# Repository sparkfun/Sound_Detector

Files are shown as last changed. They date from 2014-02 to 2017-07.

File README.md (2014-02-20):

#Sound_detector
***

[Sound Detector  
*Sound Detector*](https://www.sparkfun.com/products/12642)  

Electret microphone with multiple outputs.

* First output is the actual audio
* Second output is the amplitude envelope
* Third output is a binary "sound present" indication - high while sound is present, low otherwise.

Design and firmware files for the [VKey Voltage Keypad](https://www.sparkfun.com/products/12080).

Repository Contents
-------------------

* **/Documents** - Additional design files including LTspice simulation  
* **/Hardware** - Eagle PCB and schematic files
* **/Production** - Production panel file
* **/Software** - Arduino example code

License Information
-------------------
The hardware is released under [Creative Commons ShareAlike 4.0 International](https://creativecommons.org/licenses/by-sa/4.0/).
The code is beerware; if you see me (or any other SparkFun employee) at the local, and you've found our code helpful, please buy us a round!

Distributed as-is; no warranty is given.

Author: Byron Jacquot @ SparkFun Electonics

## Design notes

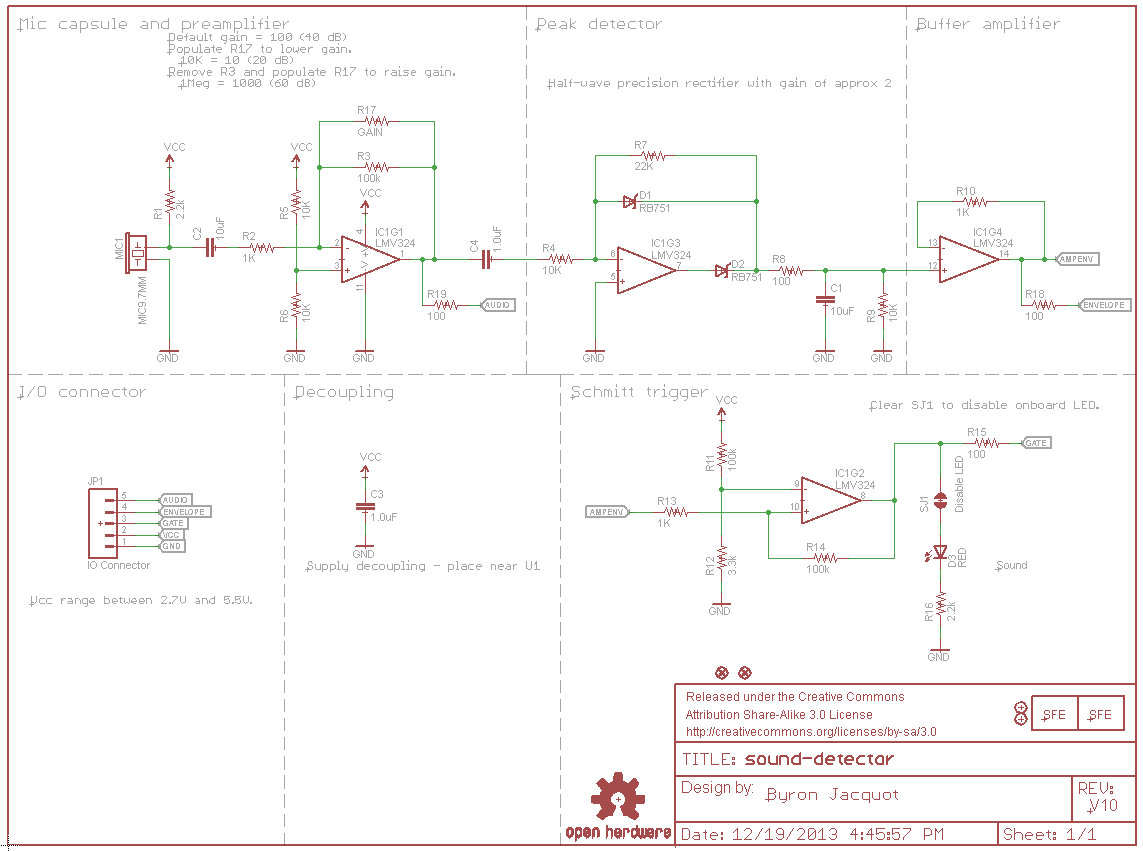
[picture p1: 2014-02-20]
documents/pix/schem.png

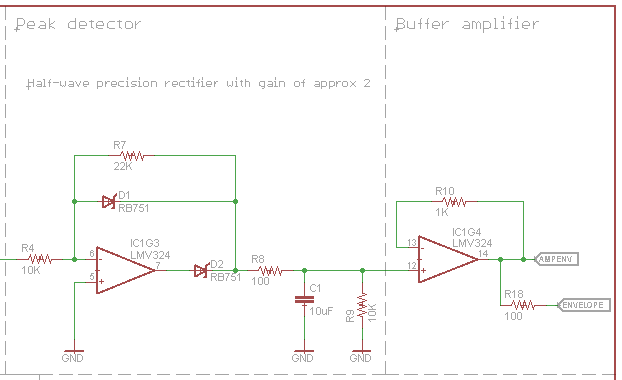
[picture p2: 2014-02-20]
documents/pix/schem2.png

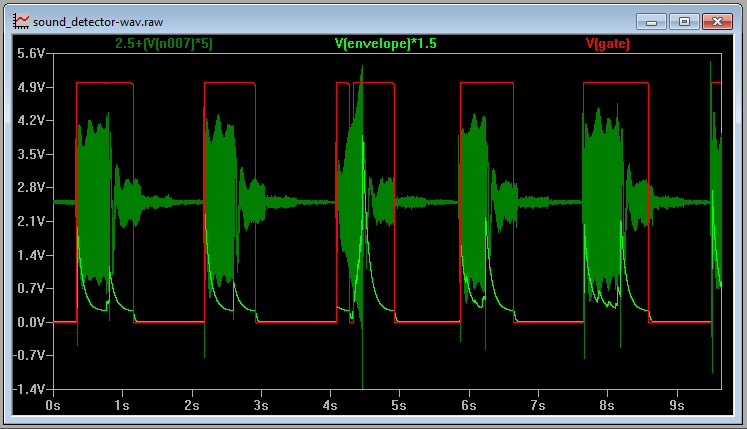
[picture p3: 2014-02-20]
documents/pix/waves.png

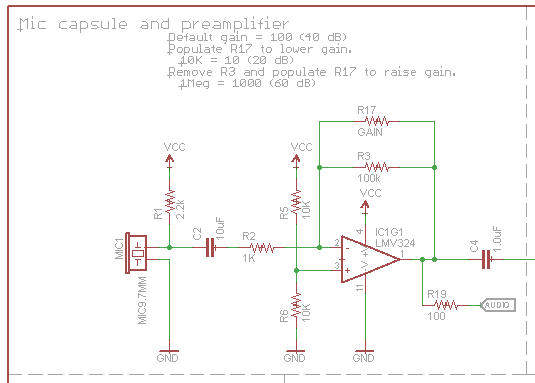
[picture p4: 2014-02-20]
documents/pix/schem1.png

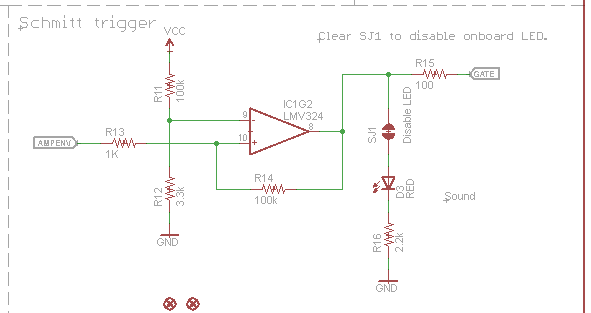
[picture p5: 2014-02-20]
documents/pix/schem3.png

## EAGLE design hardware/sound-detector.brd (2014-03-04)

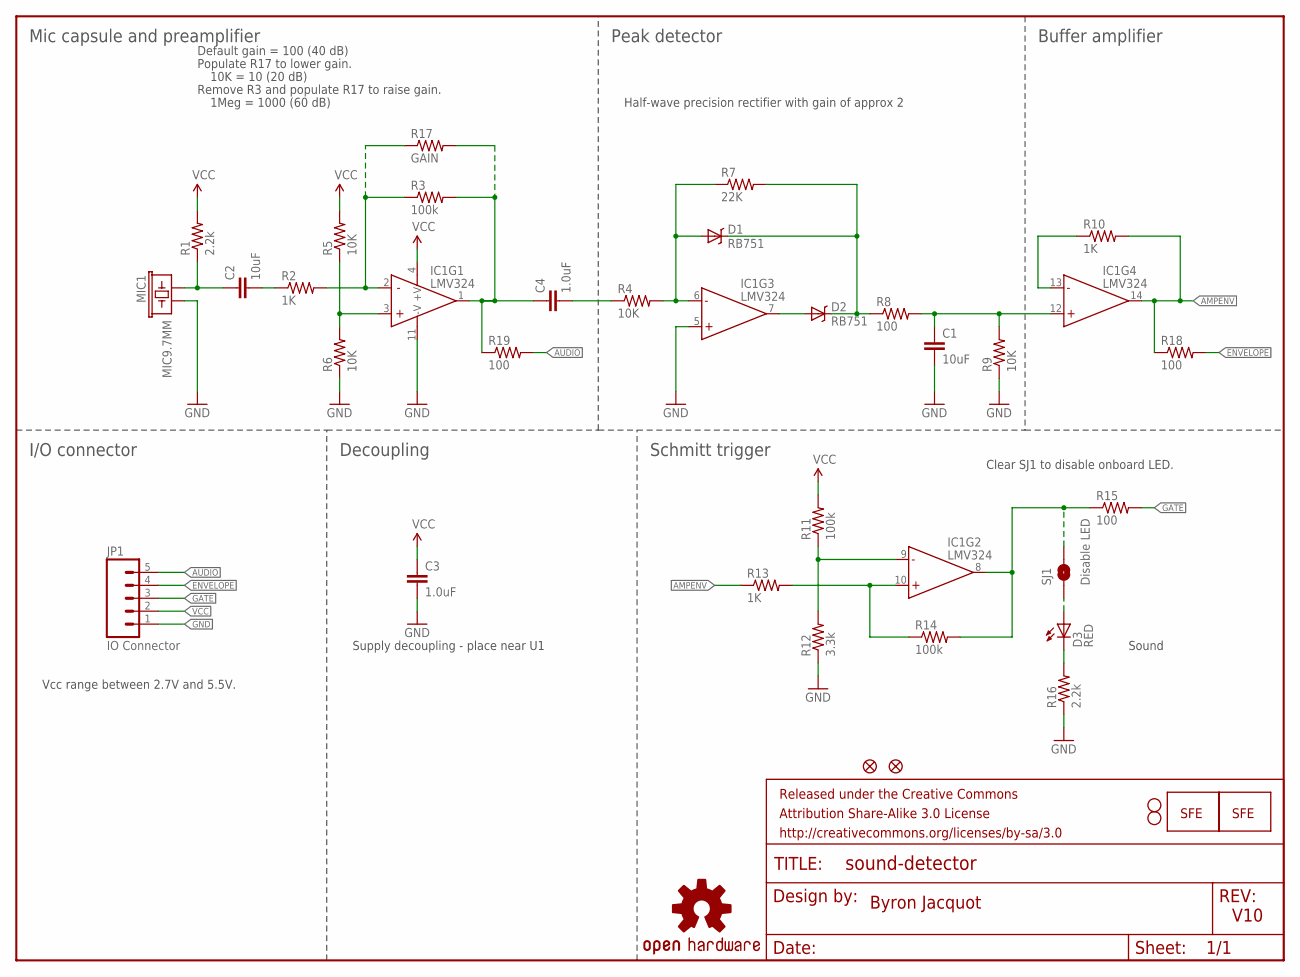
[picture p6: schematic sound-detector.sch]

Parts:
C1, C2: 10uF; 1206
C3, C4: 1.0uF; 0603-CAP
D1, D2: RB751; SOD-523
D3: RED; LED-0603
FID3, FID4: FIDUCIAL1X2; FIDUCIAL-1X2
FRAME1: FRAME-LETTER; CREATIVE_COMMONS
IC1: LMV324; SO014
JP1: IO Connector; 1X05
LOGO1: OSHW-LOGOM; OSHW-LOGO-M
LOGO2: LOGO-SFENW2; SFE-NEW-WEB
LOGO3: LOGO-SFESK; SFE-LOGO-FLAME
MIC1: MIC9.7MM; MIC-9.7MM
R1, R16: 2.2k; 0603-RES
R2, R10, R13: 1K; 0603-RES
R3, R11, R14: 100k; 0603-RES
R4, R5, R6, R9: 10K; 0603-RES
R7: 22K; 0603-RES
R8, R15, R18, R19: 100; 0603-RES
R12: 3.3k; 0603-RES
R17: GAIN; AXIAL-0.1EZ
SJ1: Disable LED; SJ_2S
STANDOFF1, STANDOFF2: STAND-OFF

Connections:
AMPENV: IC1.14 (OUT), R10.2, R13.1, R18.1
AUDIO: JP1.5, R19.2
ENVELOPE: JP1.4, R18.2
GATE: JP1.3, R15.2
GND: C1.2, C3.2, IC1.5 (+IN), IC1.11 (-V), JP1.1, MIC1.2, R6.1, R9.1, R12.1, R16.1
N$: C4.1, IC1.1 (OUT), R3.2, R17.P$2 (2), R19.1
unnamed: C2.1, MIC1.1, R1.1
unnamed: IC1.3 (+IN), R5.1, R6.2
unnamed: D3.C, R16.2
unnamed: IC1.2 (-IN), R2.2, R3.1, R17.P$1 (1)
unnamed: C2.2, R2.1
unnamed: C4.2, R4.1
unnamed: D1.A, IC1.6 (-IN), R4.2, R7.1
unnamed: D2.A, IC1.7 (OUT)
unnamed: D1.C, D2.C, R7.2, R8.1
unnamed: C1.1, IC1.12 (+IN), R8.2, R9.2
unnamed: IC1.13 (-IN), R10.1
unnamed: D3.A, SJ1.1
unnamed: IC1.9 (-IN), R11.1, R12.2
unnamed: IC1.10 (+IN), R13.2, R14.1
unnamed: IC1.8 (OUT), R14.2, R15.1, SJ1.2
VCC: C3.1, IC1.4 (+V), JP1.2, R1.2, R5.2, R11.2

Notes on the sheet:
Byron Jacquot
V10
Supply decoupling - place near U1
Mic capsule and preamplifier
Peak detector
Buffer amplifier
I/O connector
Decoupling
Schmitt trigger
Default gain = 100 (40 dB)
Half-wave precision rectifier with gain of approx 2
Vcc range between 2.7V and 5.5V.
Sound
Populate R17 to lower gain.
10K = 10 (20 dB)
Remove R3 and populate R17 to raise gain.
1Meg = 1000 (60 dB)
Clear SJ1 to disable onboard LED.

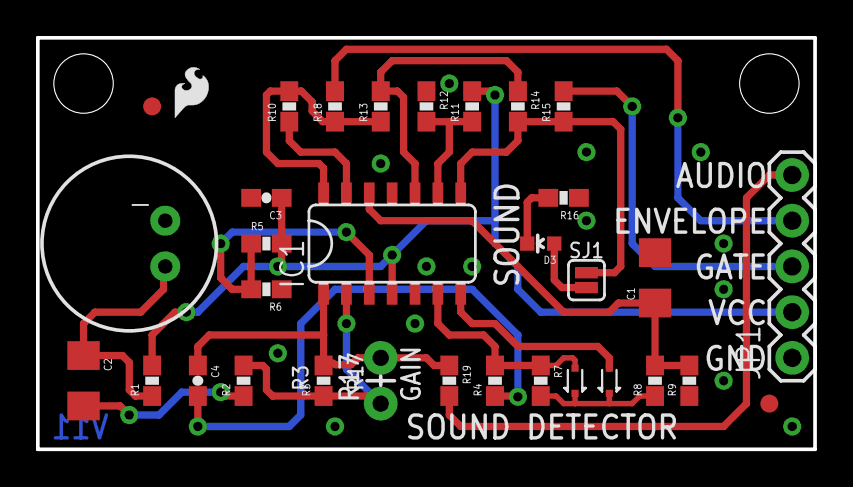
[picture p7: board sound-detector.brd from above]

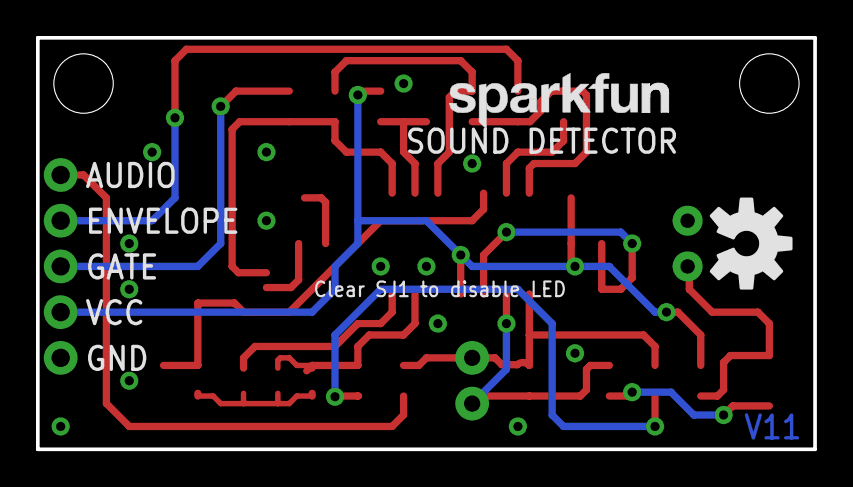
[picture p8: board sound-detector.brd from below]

Board: 2 copper layers, 43.2 x 22.9 mm, 38 parts (2 on the bottom side), 22 nets.

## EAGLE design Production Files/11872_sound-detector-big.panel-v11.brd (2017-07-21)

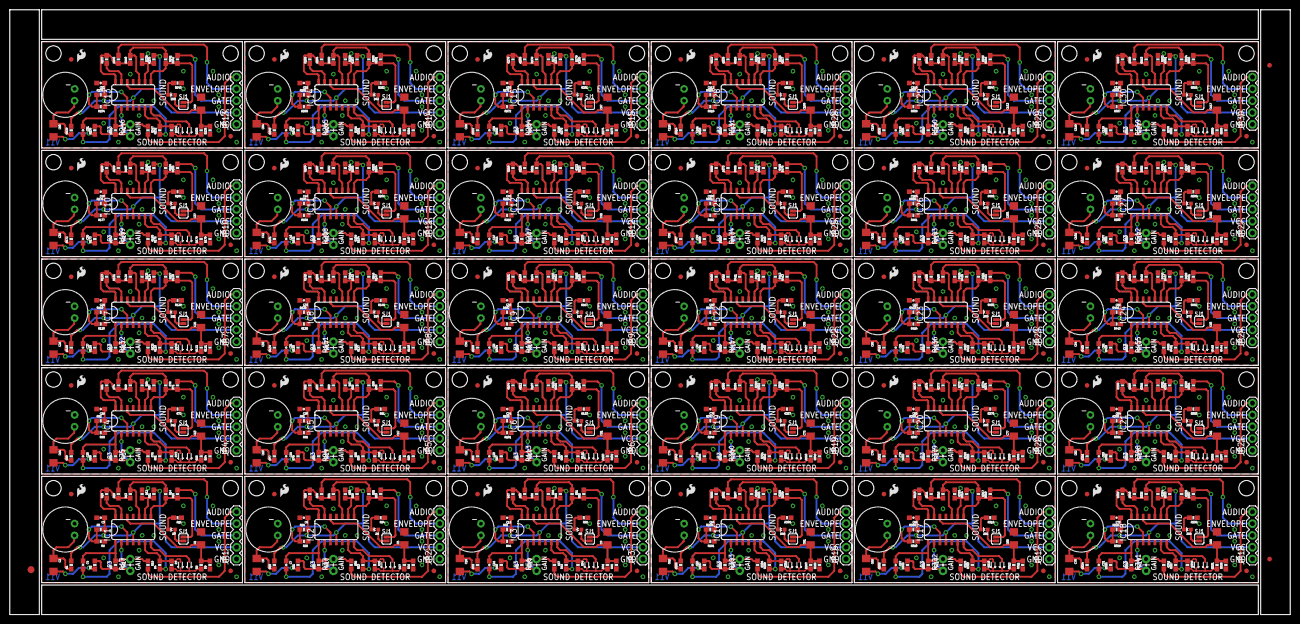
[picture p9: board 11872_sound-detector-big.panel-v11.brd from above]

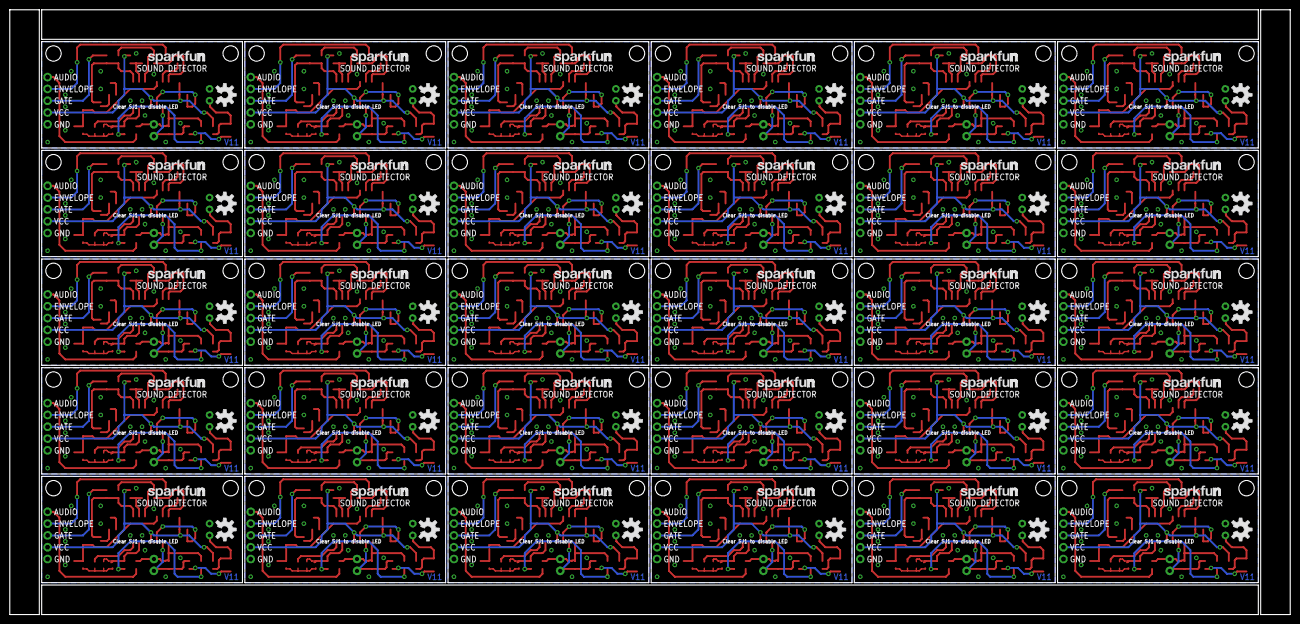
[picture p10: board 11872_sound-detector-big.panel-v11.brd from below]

Board: 2 copper layers, 275.3 x 130.0 mm, 1113 parts (60 on the bottom side), 660 nets.

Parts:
C1, C2, C5, C6, C9, C10, C13, C14, C17, C18, C21, C22, C25, C26, C29, C30, C33, C34, C37, C38, C41, C42, C45, C46, C49, C50, C53, C54, C57, C58, C61, C62, C65, C66, C69, C70, C73, C74, C77, C78, C81, C82, C85, C86, C89, C90, C93, C94, C97, C98, C101, C102, C105, C106, C109, C110, C113, C114, C117, C118: 10uF; 1206
C3, C4, C7, C8, C11, C12, C15, C16, C19, C20, C23, C24, C27, C28, C31, C32, C35, C36, C39, C40, C43, C44, C47, C48, C51, C52, C55, C56, C59, C60, C63, C64, C67, C68, C71, C72, C75, C76, C79, C80, C83, C84, C87, C88, C91, C92, C95, C96, C99, C100, C103, C104, C107, C108, C111, C112, C115, C116, C119, C120: 1.0uF; 0603-CAP
D1, D2, D4, D5, D7, D8, D10, D11, D13, D14, D16, D17, D19, D20, D22, D23, D25, D26, D28, D29, D31, D32, D34, D35, D37, D38, D40, D41, D43, D44, D46, D47, D49, D50, D52, D53, D55, D56, D58, D59, D61, D62, D64, D65, D67, D68, D70, D71, D73, D74, D76, D77, D79, D80, D82, D83, D85, D86, D88, D89: RB751; SOD-523
D3, D6, D9, D12, D15, D18, D21, D24, D27, D30, D33, D36, D39, D42, D45, D48, D51, D54, D57, D60, D63, D66, D69, D72, D75, D78, D81, D84, D87, D90: RED; LED-0603
E$1: FIDUCIAL-1.5X3
E$4, E$6: FIDUCIAL-1X2
FID1, FID2, FID3, FID4, FID5, FID6, FID7, FID8, FID9, FID10, FID11, FID12, FID13, FID14, FID15, FID16, FID17, FID18, FID19, FID20, FID21, FID22, FID23, FID24, FID25, FID26, FID27, FID28, FID29, FID30, FID31, FID32, FID33, FID34, FID35, FID36, FID37, FID38, FID39, FID40, FID41, FID42, FID43, FID44, FID45, FID46, FID47, FID48, FID49, FID50, FID51, FID52, FID53, FID54, FID55, FID56, FID57, FID58, FID59, FID60: FIDUCIAL1X2; FIDUCIAL-1X2
IC1, IC2, IC3, IC4, IC5, IC6, IC7, IC8, IC9, IC10, IC11, IC12, IC13, IC14, IC15, IC16, IC17, IC18, IC19, IC20, IC21, IC22, IC23, IC24, IC25, IC26, IC27, IC28, IC29, IC30: LMV324; SO014
JP1, JP2, JP3, JP4, JP5, JP6, JP7, JP8, JP9, JP10, JP11, JP12, JP13, JP14, JP15, JP16, JP17, JP18, JP19, JP20, JP21, JP22, JP23, JP24, JP25, JP26, JP27, JP28, JP29, JP30: IO Connector; 1X05
LOGO1, LOGO4, LOGO7, LOGO10, LOGO13, LOGO16, LOGO19, LOGO22, LOGO25, LOGO28, LOGO31, LOGO34, LOGO37, LOGO40, LOGO43, LOGO46, LOGO49, LOGO52, LOGO55, LOGO58, LOGO61, LOGO64, LOGO67, LOGO70, LOGO73, LOGO76, LOGO79, LOGO82, LOGO85, LOGO88: OSHW-LOGOM; OSHW-LOGO-M
LOGO2, LOGO5, LOGO8, LOGO11, LOGO14, LOGO17, LOGO20, LOGO23, LOGO26, LOGO29, LOGO32, LOGO35, LOGO38, LOGO41, LOGO44, LOGO47, LOGO50, LOGO53, LOGO56, LOGO59, LOGO62, LOGO65, LOGO68, LOGO71, LOGO74, LOGO77, LOGO80, LOGO83, LOGO86, LOGO89: LOGO-SFENW2; SFE-NEW-WEB
LOGO3, LOGO6, LOGO9, LOGO12, LOGO15, LOGO18, LOGO21, LOGO24, LOGO27, LOGO30, LOGO33, LOGO36, LOGO39, LOGO42, LOGO45, LOGO48, LOGO51, LOGO54, LOGO57, LOGO60, LOGO63, LOGO66, LOGO69, LOGO72, LOGO75, LOGO78, LOGO81, LOGO84, LOGO87, LOGO90: LOGO-SFESK; SFE-LOGO-FLAME
MIC1, MIC2, MIC3, MIC4, MIC5, MIC6, MIC7, MIC8, MIC9, MIC10, MIC11, MIC12, MIC13, MIC14, MIC15, MIC16, MIC17, MIC18, MIC19, MIC20, MIC21, MIC22, MIC23, MIC24, MIC25, MIC26, MIC27, MIC28, MIC29, MIC30: MIC9.7MM; MIC-9.7MM
R1, R16, R20, R34, R39, R53, R58, R72, R77, R91, R96, R110, R115, R129, R134, R148, R153, R167, R172, R186, R191, R205, R210, R224, R229, R243, R248, R262, R267, R281, R286, R300, R305, R319, R324, R338, R343, R357, R362, R376, R381, R395, R400, R414, R419, R433, R438, R452, R457, R471, R476, R490, R495, R509, R514, R528, R533, R547, R552, R566: 2.2k; 0603-RES
R2, R10, R13, R21, R28, R31, R40, R47, R50, R59, R66, R69, R78, R85, R88, R97, R104, R107, R116, R123, R126, R135, R142, R145, R154, R161, R164, R173, R180, R183, R192, R199, R202, R211, R218, R221, R230, R237, R240, R249, R256, R259, R268, R275, R278, R287, R294, R297, R306, R313, R316, R325, R332, R335, R344, R351, R354, R363, R370, R373, R382, R389, R392, R401, R408, R411, R420, R427, R430, R439, R446, R449, R458, R465, R468, R477, R484, R487, R496, R503, R506, R515, R522, R525, R534, R541, R544, R553, R560, R563: 1K; 0603-RES
R3, R11, R14, R22, R29, R32, R41, R48, R51, R60, R67, R70, R79, R86, R89, R98, R105, R108, R117, R124, R127, R136, R143, R146, R155, R162, R165, R174, R181, R184, R193, R200, R203, R212, R219, R222, R231, R238, R241, R250, R257, R260, R269, R276, R279, R288, R295, R298, R307, R314, R317, R326, R333, R336, R345, R352, R355, R364, R371, R374, R383, R390, R393, R402, R409, R412, R421, R428, R431, R440, R447, R450, R459, R466, R469, R478, R485, R488, R497, R504, R507, R516, R523, R526, R535, R542, R545, R554, R561, R564: 100k; 0603-RES
R4, R5, R6, R9, R23, R24, R25, R26, R42, R43, R44, R45, R61, R62, R63, R64, R80, R81, R82, R83, R99, R100, R101, R102, R118, R119, R120, R121, R137, R138, R139, R140, R156, R157, R158, R159, R175, R176, R177, R178, R194, R195, R196, R197, R213, R214, R215, R216, R232, R233, R234, R235, R251, R252, R253, R254, R270, R271, R272, R273, R289, R290, R291, R292, R308, R309, R310, R311, R327, R328, R329, R330, R346, R347, R348, R349, R365, R366, R367, R368, R384, R385, R386, R387, R403, R404, R405, R406, R422, R423, R424, R425, R441, R442, R443, R444, R460, R461, R462, R463, R479, R480, R481, R482, R498, R499, R500, R501, R517, R518, R519, R520, R536, R537, R538, R539, R555, R556, R557, R558: 10K; 0603-RES
R7, R35, R54, R73, R92, R111, R130, R149, R168, R187, R206, R225, R244, R263, R282, R301, R320, R339, R358, R377, R396, R415, R434, R453, R472, R491, R510, R529, R548, R567: 22K; 0603-RES
R8, R15, R18, R19, R27, R33, R36, R38, R46, R52, R55, R57, R65, R71, R74, R76, R84, R90, R93, R95, R103, R109, R112, R114, R122, R128, R131, R133, R141, R147, R150, R152, R160, R166, R169, R171, R179, R185, R188, R190, R198, R204, R207, R209, R217, R223, R226, R228, R236, R242, R245, R247, R255, R261, R264, R266, R274, R280, R283, R285, R293, R299, R302, R304, R312, R318, R321, R323, R331, R337, R340, R342, R350, R356, R359, R361, R369, R375, R378, R380, R388, R394, R397, R399, R407, R413, R416, R418, R426, R432, R435, R437, R445, R451, R454, R456, R464, R470, R473, R475, R483, R489, R492, R494, R502, R508, R511, R513, R521, R527, R530, R532, R540, R546, R549, R551, R559, R565, R568, R570: 100; 0603-RES
R12, R30, R49, R68, R87, R106, R125, R144, R163, R182, R201, R220, R239, R258, R277, R296, R315, R334, R353, R372, R391, R410, R429, R448, R467, R486, R505, R524, R543, R562: 3.3k; 0603-RES
R17, R37, R56, R75, R94, R113, R132, R151, R170, R189, R208, R227, R246, R265, R284, R303, R322, R341, R360, R379, R398, R417, R436, R455, R474, R493, R512, R531, R550, R569: GAIN; AXIAL-0.1EZ
SJ1, SJ2, SJ3, SJ4, SJ5, SJ6, SJ7, SJ8, SJ9, SJ10, SJ11, SJ12, SJ13, SJ14, SJ15, SJ16, SJ17, SJ18, SJ19, SJ20, SJ21, SJ22, SJ23, SJ24, SJ25, SJ26, SJ27, SJ28, SJ29, SJ30: Disable LED; SJ_2S
STANDOFF1, STANDOFF2, STANDOFF3, STANDOFF4, STANDOFF5, STANDOFF6, STANDOFF7, STANDOFF8, STANDOFF9, STANDOFF10, STANDOFF11, STANDOFF12, STANDOFF13, STANDOFF14, STANDOFF15, STANDOFF16, STANDOFF17, STANDOFF18, STANDOFF19, STANDOFF20, STANDOFF21, STANDOFF22, STANDOFF23, STANDOFF24, STANDOFF25, STANDOFF26, STANDOFF27, STANDOFF28, STANDOFF29, STANDOFF30, STANDOFF31, STANDOFF32, STANDOFF33, STANDOFF34, STANDOFF35, STANDOFF36, STANDOFF37, STANDOFF38, STANDOFF39, STANDOFF40, STANDOFF41, STANDOFF42, STANDOFF43, STANDOFF44, STANDOFF45, STANDOFF46, STANDOFF47, STANDOFF48, STANDOFF49, STANDOFF50, STANDOFF51, STANDOFF52, STANDOFF53, STANDOFF54, STANDOFF55, STANDOFF56, STANDOFF57, STANDOFF58, STANDOFF59, STANDOFF60: STAND-OFF

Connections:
AMPENV: IC1.14, R10.2, R13.1, R18.1
AMPENV1: IC2.14, R28.2, R31.1, R36.1
AMPENV2: IC3.14, R47.2, R50.1, R55.1
AMPENV3: IC4.14, R66.2, R69.1, R74.1
AMPENV4: IC5.14, R85.2, R88.1, R93.1
AMPENV5: IC6.14, R104.2, R107.1, R112.1
AMPENV6: IC7.14, R123.2, R126.1, R131.1
AMPENV7: IC8.14, R142.2, R145.1, R150.1
AMPENV8: IC9.14, R161.2, R164.1, R169.1
AMPENV9: IC10.14, R180.2, R183.1, R188.1
AMPENV10: IC11.14, R199.2, R202.1, R207.1
AMPENV11: IC12.14, R218.2, R221.1, R226.1
AMPENV12: IC13.14, R237.2, R240.1, R245.1
AMPENV13: IC14.14, R256.2, R259.1, R264.1
AMPENV14: IC15.14, R275.2, R278.1, R283.1
AMPENV15: IC16.14, R294.2, R297.1, R302.1
AMPENV16: IC17.14, R313.2, R316.1, R321.1
AMPENV17: IC18.14, R332.2, R335.1, R340.1
AMPENV18: IC19.14, R351.2, R354.1, R359.1
AMPENV19: IC20.14, R370.2, R373.1, R378.1
AMPENV20: IC21.14, R389.2, R392.1, R397.1
AMPENV21: IC22.14, R408.2, R411.1, R416.1
AMPENV22: IC23.14, R427.2, R430.1, R435.1
AMPENV23: IC24.14, R446.2, R449.1, R454.1
AMPENV24: IC25.14, R465.2, R468.1, R473.1
AMPENV25: IC26.14, R484.2, R487.1, R492.1
AMPENV26: IC27.14, R503.2, R506.1, R511.1
AMPENV27: IC28.14, R522.2, R525.1, R530.1
AMPENV28: IC29.14, R541.2, R544.1, R549.1
AMPENV29: IC30.14, R560.2, R563.1, R568.1
AUDIO: JP1.5, R19.2
AUDIO1: JP2.5, R38.2
AUDIO2: JP3.5, R57.2
AUDIO3: JP4.5, R76.2
AUDIO4: JP5.5, R95.2
AUDIO5: JP6.5, R114.2
AUDIO6: JP7.5, R133.2
AUDIO7: JP8.5, R152.2
AUDIO8: JP9.5, R171.2
AUDIO9: JP10.5, R190.2
AUDIO10: JP11.5, R209.2
AUDIO11: JP12.5, R228.2
AUDIO12: JP13.5, R247.2
AUDIO13: JP14.5, R266.2
AUDIO14: JP15.5, R285.2
AUDIO15: JP16.5, R304.2
AUDIO16: JP17.5, R323.2
AUDIO17: JP18.5, R342.2
AUDIO18: JP19.5, R361.2
AUDIO19: JP20.5, R380.2
AUDIO20: JP21.5, R399.2
AUDIO21: JP22.5, R418.2
AUDIO22: JP23.5, R437.2
AUDIO23: JP24.5, R456.2
AUDIO24: JP25.5, R475.2
AUDIO25: JP26.5, R494.2
AUDIO26: JP27.5, R513.2
AUDIO27: JP28.5, R532.2
AUDIO28: JP29.5, R551.2
AUDIO29: JP30.5, R570.2
ENVELOPE: JP1.4, R18.2
ENVELOPE1: JP2.4, R36.2
ENVELOPE2: JP3.4, R55.2
ENVELOPE3: JP4.4, R74.2
ENVELOPE4: JP5.4, R93.2
ENVELOPE5: JP6.4, R112.2
ENVELOPE6: JP7.4, R131.2
ENVELOPE7: JP8.4, R150.2
ENVELOPE8: JP9.4, R169.2
ENVELOPE9: JP10.4, R188.2
ENVELOPE10: JP11.4, R207.2
ENVELOPE11: JP12.4, R226.2
ENVELOPE12: JP13.4, R245.2
ENVELOPE13: JP14.4, R264.2
ENVELOPE14: JP15.4, R283.2
ENVELOPE15: JP16.4, R302.2
ENVELOPE16: JP17.4, R321.2
ENVELOPE17: JP18.4, R340.2
ENVELOPE18: JP19.4, R359.2
ENVELOPE19: JP20.4, R378.2
ENVELOPE20: JP21.4, R397.2
ENVELOPE21: JP22.4, R416.2
ENVELOPE22: JP23.4, R435.2
ENVELOPE23: JP24.4, R454.2
ENVELOPE24: JP25.4, R473.2
ENVELOPE25: JP26.4, R492.2
ENVELOPE26: JP27.4, R511.2
ENVELOPE27: JP28.4, R530.2
ENVELOPE28: JP29.4, R549.2
ENVELOPE29: JP30.4, R568.2
GATE: JP1.3, R15.2
GATE1: JP2.3, R33.2
GATE2: JP3.3, R52.2
GATE3: JP4.3, R71.2
GATE4: JP5.3, R90.2
GATE5: JP6.3, R109.2
GATE6: JP7.3, R128.2
GATE7: JP8.3, R147.2
GATE8: JP9.3, R166.2
GATE9: JP10.3, R185.2
GATE10: JP11.3, R204.2
GATE11: JP12.3, R223.2
GATE12: JP13.3, R242.2
GATE13: JP14.3, R261.2
GATE14: JP15.3, R280.2
GATE15: JP16.3, R299.2
GATE16: JP17.3, R318.2
GATE17: JP18.3, R337.2
GATE18: JP19.3, R356.2
GATE19: JP20.3, R375.2
GATE20: JP21.3, R394.2
GATE21: JP22.3, R413.2
GATE22: JP23.3, R432.2
GATE23: JP24.3, R451.2
GATE24: JP25.3, R470.2
GATE25: JP26.3, R489.2
GATE26: JP27.3, R508.2
GATE27: JP28.3, R527.2
GATE28: JP29.3, R546.2
GATE29: JP30.3, R565.2
GND: C1.2, C3.2, IC1.5, IC1.11, JP1.1, MIC1.2, R6.1, R9.1, R12.1, R16.1
GND1: C5.2, C8.2, IC2.5, IC2.11, JP2.1, MIC2.2, R25.1, R26.1, R30.1, R34.1
GND2: C9.2, C12.2, IC3.5, IC3.11, JP3.1, MIC3.2, R44.1, R45.1, R49.1, R53.1
GND3: C13.2, C16.2, IC4.5, IC4.11, JP4.1, MIC4.2, R63.1, R64.1, R68.1, R72.1
GND4: C17.2, C20.2, IC5.5, IC5.11, JP5.1, MIC5.2, R82.1, R83.1, R87.1, R91.1
GND5: C21.2, C24.2, IC6.5, IC6.11, JP6.1, MIC6.2, R101.1, R102.1, R106.1, R110.1
GND6: C25.2, C28.2, IC7.5, IC7.11, JP7.1, MIC7.2, R120.1, R121.1, R125.1, R129.1
GND7: C29.2, C32.2, IC8.5, IC8.11, JP8.1, MIC8.2, R139.1, R140.1, R144.1, R148.1
GND8: C33.2, C36.2, IC9.5, IC9.11, JP9.1, MIC9.2, R158.1, R159.1, R163.1, R167.1
GND9: C37.2, C40.2, IC10.5, IC10.11, JP10.1, MIC10.2, R177.1, R178.1, R182.1, R186.1
GND10: C41.2, C44.2, IC11.5, IC11.11, JP11.1, MIC11.2, R196.1, R197.1, R201.1, R205.1
GND11: C45.2, C48.2, IC12.5, IC12.11, JP12.1, MIC12.2, R215.1, R216.1, R220.1, R224.1
GND12: C49.2, C52.2, IC13.5, IC13.11, JP13.1, MIC13.2, R234.1, R235.1, R239.1, R243.1
GND13: C53.2, C56.2, IC14.5, IC14.11, JP14.1, MIC14.2, R253.1, R254.1, R258.1, R262.1
GND14: C57.2, C60.2, IC15.5, IC15.11, JP15.1, MIC15.2, R272.1, R273.1, R277.1, R281.1
GND15: C61.2, C64.2, IC16.5, IC16.11, JP16.1, MIC16.2, R291.1, R292.1, R296.1, R300.1
GND16: C65.2, C68.2, IC17.5, IC17.11, JP17.1, MIC17.2, R310.1, R311.1, R315.1, R319.1
GND17: C69.2, C72.2, IC18.5, IC18.11, JP18.1, MIC18.2, R329.1, R330.1, R334.1, R338.1
GND18: C73.2, C76.2, IC19.5, IC19.11, JP19.1, MIC19.2, R348.1, R349.1, R353.1, R357.1
GND19: C77.2, C80.2, IC20.5, IC20.11, JP20.1, MIC20.2, R367.1, R368.1, R372.1, R376.1
GND20: C81.2, C84.2, IC21.5, IC21.11, JP21.1, MIC21.2, R386.1, R387.1, R391.1, R395.1
GND21: C85.2, C88.2, IC22.5, IC22.11, JP22.1, MIC22.2, R405.1, R406.1, R410.1, R414.1
GND22: C89.2, C92.2, IC23.5, IC23.11, JP23.1, MIC23.2, R424.1, R425.1, R429.1, R433.1
GND23: C93.2, C96.2, IC24.5, IC24.11, JP24.1, MIC24.2, R443.1, R444.1, R448.1, R452.1
GND24: C97.2, C100.2, IC25.5, IC25.11, JP25.1, MIC25.2, R462.1, R463.1, R467.1, R471.1
GND25: C101.2, C104.2, IC26.5, IC26.11, JP26.1, MIC26.2, R481.1, R482.1, R486.1, R490.1
GND26: C105.2, C108.2, IC27.5, IC27.11, JP27.1, MIC27.2, R500.1, R501.1, R505.1, R509.1
GND27: C109.2, C112.2, IC28.5, IC28.11, JP28.1, MIC28.2, R519.1, R520.1, R524.1, R528.1
GND28: C113.2, C116.2, IC29.5, IC29.11, JP29.1, MIC29.2, R538.1, R539.1, R543.1, R547.1
GND29: C117.2, C120.2, IC30.5, IC30.11, JP30.1, MIC30.2, R557.1, R558.1, R562.1, R566.1
N$: C4.1, IC1.1, R3.2, R17.P$2, R19.1
unnamed: C2.1, MIC1.1, R1.1
unnamed: IC1.3, R5.1, R6.2
unnamed: D3.C, R16.2
unnamed: IC1.2, R2.2, R3.1, R17.P$1
unnamed: C2.2, R2.1
unnamed: C4.2, R4.1
unnamed: D1.A, IC1.6, R4.2, R7.1
unnamed: D2.A, IC1.7
unnamed: D1.C, D2.C, R7.2, R8.1
unnamed: C1.1, IC1.12, R8.2, R9.2
unnamed: IC1.13, R10.1
unnamed: D3.A, SJ1.1
unnamed: C6.1, MIC2.1, R20.1
unnamed: IC2.3, R24.1, R25.2
unnamed: IC1.9, R11.1, R12.2
unnamed: IC1.10, R13.2, R14.1
unnamed: IC1.8, R14.2, R15.1, SJ1.2
unnamed: IC2.2, R21.2, R22.1, R37.P$1
unnamed: C6.2, R21.1
unnamed: C7.2, R23.1
unnamed: D4.A, IC2.6, R23.2, R35.1
unnamed: D5.A, IC2.7
unnamed: D4.C, D5.C, R27.1, R35.2
unnamed: C5.1, IC2.12, R26.2, R27.2
unnamed: IC2.13, R28.1
unnamed: IC2.9, R29.1, R30.2
unnamed: IC2.10, R31.2, R32.1
unnamed: IC2.8, R32.2, R33.1, SJ2.2
unnamed: D6.C, R34.2
unnamed: D6.A, SJ2.1
unnamed: C7.1, IC2.1, R22.2, R37.P$2, R38.1
unnamed: C10.1, MIC3.1, R39.1
unnamed: IC3.3, R43.1, R44.2
unnamed: IC3.2, R40.2, R41.1, R56.P$1
unnamed: C10.2, R40.1
unnamed: C11.2, R42.1
unnamed: D7.A, IC3.6, R42.2, R54.1
unnamed: D8.A, IC3.7
unnamed: D7.C, D8.C, R46.1, R54.2
unnamed: C9.1, IC3.12, R45.2, R46.2
unnamed: IC3.13, R47.1
unnamed: IC3.9, R48.1, R49.2
unnamed: IC3.10, R50.2, R51.1
unnamed: IC3.8, R51.2, R52.1, SJ3.2
unnamed: D9.C, R53.2
unnamed: D9.A, SJ3.1
unnamed: C11.1, IC3.1, R41.2, R56.P$2, R57.1
unnamed: C14.1, MIC4.1, R58.1
unnamed: IC4.3, R62.1, R63.2
unnamed: IC4.2, R59.2, R60.1, R75.P$1
unnamed: C14.2, R59.1
unnamed: C15.2, R61.1
unnamed: D10.A, IC4.6, R61.2, R73.1
unnamed: D11.A, IC4.7
unnamed: D10.C, D11.C, R65.1, R73.2
unnamed: C13.1, IC4.12, R64.2, R65.2
unnamed: IC4.13, R66.1
unnamed: IC4.9, R67.1, R68.2
unnamed: IC4.10, R69.2, R70.1
unnamed: IC4.8, R70.2, R71.1, SJ4.2
unnamed: D12.C, R72.2
unnamed: D12.A, SJ4.1
unnamed: C15.1, IC4.1, R60.2, R75.P$2, R76.1
unnamed: C18.1, MIC5.1, R77.1
unnamed: IC5.3, R81.1, R82.2
unnamed: IC5.2, R78.2, R79.1, R94.P$1
unnamed: C18.2, R78.1
unnamed: C19.2, R80.1
unnamed: D13.A, IC5.6, R80.2, R92.1
unnamed: D14.A, IC5.7
unnamed: D13.C, D14.C, R84.1, R92.2
unnamed: C17.1, IC5.12, R83.2, R84.2
unnamed: IC5.13, R85.1
unnamed: IC5.9, R86.1, R87.2
unnamed: IC5.10, R88.2, R89.1
unnamed: IC5.8, R89.2, R90.1, SJ5.2
unnamed: D15.C, R91.2
unnamed: D15.A, SJ5.1
unnamed: C19.1, IC5.1, R79.2, R94.P$2, R95.1
unnamed: C22.1, MIC6.1, R96.1
unnamed: IC6.3, R100.1, R101.2
unnamed: IC6.2, R97.2, R98.1, R113.P$1
unnamed: C22.2, R97.1
unnamed: C23.2, R99.1
unnamed: D16.A, IC6.6, R99.2, R111.1
unnamed: D17.A, IC6.7
unnamed: D16.C, D17.C, R103.1, R111.2
unnamed: C21.1, IC6.12, R102.2, R103.2
unnamed: IC6.13, R104.1
unnamed: IC6.9, R105.1, R106.2
unnamed: IC6.10, R107.2, R108.1
unnamed: IC6.8, R108.2, R109.1, SJ6.2
unnamed: D18.C, R110.2
unnamed: D18.A, SJ6.1
unnamed: C23.1, IC6.1, R98.2, R113.P$2, R114.1
unnamed: C26.1, MIC7.1, R115.1
unnamed: IC7.3, R119.1, R120.2
unnamed: IC7.2, R116.2, R117.1, R132.P$1
unnamed: C26.2, R116.1
unnamed: C27.2, R118.1
unnamed: D19.A, IC7.6, R118.2, R130.1
unnamed: D20.A, IC7.7
unnamed: D19.C, D20.C, R122.1, R130.2
unnamed: C25.1, IC7.12, R121.2, R122.2
unnamed: IC7.13, R123.1
unnamed: IC7.9, R124.1, R125.2
unnamed: IC7.10, R126.2, R127.1
unnamed: IC7.8, R127.2, R128.1, SJ7.2
unnamed: D21.C, R129.2
unnamed: D21.A, SJ7.1
unnamed: C27.1, IC7.1, R117.2, R132.P$2, R133.1
unnamed: C30.1, MIC8.1, R134.1
unnamed: IC8.3, R138.1, R139.2
unnamed: IC8.2, R135.2, R136.1, R151.P$1
unnamed: C30.2, R135.1
unnamed: C31.2, R137.1
unnamed: D22.A, IC8.6, R137.2, R149.1
unnamed: D23.A, IC8.7
unnamed: D22.C, D23.C, R141.1, R149.2
unnamed: C29.1, IC8.12, R140.2, R141.2
unnamed: IC8.13, R142.1
unnamed: IC8.9, R143.1, R144.2
unnamed: IC8.10, R145.2, R146.1
unnamed: IC8.8, R146.2, R147.1, SJ8.2
unnamed: D24.C, R148.2
unnamed: D24.A, SJ8.1
unnamed: C31.1, IC8.1, R136.2, R151.P$2, R152.1
unnamed: C34.1, MIC9.1, R153.1
unnamed: IC9.3, R157.1, R158.2
unnamed: IC9.2, R154.2, R155.1, R170.P$1
unnamed: C34.2, R154.1
unnamed: C35.2, R156.1
unnamed: D25.A, IC9.6, R156.2, R168.1
unnamed: D26.A, IC9.7
unnamed: D25.C, D26.C, R160.1, R168.2
unnamed: C33.1, IC9.12, R159.2, R160.2
unnamed: IC9.13, R161.1
unnamed: IC9.9, R162.1, R163.2
unnamed: IC9.10, R164.2, R165.1
unnamed: IC9.8, R165.2, R166.1, SJ9.2
unnamed: D27.C, R167.2
unnamed: D27.A, SJ9.1
unnamed: C35.1, IC9.1, R155.2, R170.P$2, R171.1
unnamed: C38.1, MIC10.1, R172.1
unnamed: IC10.3, R176.1, R177.2
unnamed: IC10.2, R173.2, R174.1, R189.P$1
unnamed: C38.2, R173.1
unnamed: C39.2, R175.1
unnamed: D28.A, IC10.6, R175.2, R187.1
unnamed: D29.A, IC10.7
unnamed: D28.C, D29.C, R179.1, R187.2
unnamed: C37.1, IC10.12, R178.2, R179.2
unnamed: IC10.13, R180.1
unnamed: IC10.9, R181.1, R182.2
unnamed: IC10.10, R183.2, R184.1
unnamed: IC10.8, R184.2, R185.1, SJ10.2
unnamed: D30.C, R186.2
unnamed: D30.A, SJ10.1
unnamed: C39.1, IC10.1, R174.2, R189.P$2, R190.1
unnamed: C42.1, MIC11.1, R191.1
unnamed: IC11.3, R195.1, R196.2
unnamed: IC11.2, R192.2, R193.1, R208.P$1
unnamed: C42.2, R192.1
unnamed: C43.2, R194.1
unnamed: D31.A, IC11.6, R194.2, R206.1
unnamed: D32.A, IC11.7
unnamed: D31.C, D32.C, R198.1, R206.2
unnamed: C41.1, IC11.12, R197.2, R198.2
unnamed: IC11.13, R199.1
unnamed: IC11.9, R200.1, R201.2
unnamed: IC11.10, R202.2, R203.1
unnamed: IC11.8, R203.2, R204.1, SJ11.2
unnamed: D33.C, R205.2
unnamed: D33.A, SJ11.1
unnamed: C43.1, IC11.1, R193.2, R208.P$2, R209.1
unnamed: C46.1, MIC12.1, R210.1
unnamed: IC12.3, R214.1, R215.2
unnamed: IC12.2, R211.2, R212.1, R227.P$1
unnamed: C46.2, R211.1
unnamed: C47.2, R213.1
unnamed: D34.A, IC12.6, R213.2, R225.1
unnamed: D35.A, IC12.7
unnamed: D34.C, D35.C, R217.1, R225.2
unnamed: C45.1, IC12.12, R216.2, R217.2
unnamed: IC12.13, R218.1
unnamed: IC12.9, R219.1, R220.2
unnamed: IC12.10, R221.2, R222.1
unnamed: IC12.8, R222.2, R223.1, SJ12.2
unnamed: D36.C, R224.2
unnamed: D36.A, SJ12.1
unnamed: C47.1, IC12.1, R212.2, R227.P$2, R228.1
unnamed: C50.1, MIC13.1, R229.1
unnamed: IC13.3, R233.1, R234.2
unnamed: IC13.2, R230.2, R231.1, R246.P$1
unnamed: C50.2, R230.1
unnamed: C51.2, R232.1
unnamed: D37.A, IC13.6, R232.2, R244.1
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

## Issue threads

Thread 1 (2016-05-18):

How sensitive is microphone?

gwpl, 2016-05-18:
I am looking for device capable for recognizing very delicate quite sounds. Are there any specs about properties of microphone used in given set?

Jacquot-SFE, 2016-05-18:
The microphone element is the electret that we sell, the same as on our electret microphone breakout.

The datasheet for it is here:
http://cdn.sparkfun.com/datasheets/Sensors/Sound/CEM-C9745JAD462P2.54R.pdf

Closed 2016-05-18.

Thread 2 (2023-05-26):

Formula to calculate sound pressure level in dB?

T-vK, 2023-05-26:
What's the formula to calculate the sound pressure level in dB that the sensor is currently picking up?

I'm setting the gain on pin r17 using a digital potentiometer. In my code I have the variables `gainDb`, `rawAudioVolume` and `rawEnvelopeVolume` available. How do I calculate the sound pressure level / volume from that?

``` C++
/**
 * gain: A number between 0 and 33
 * rawAudioVolume: A number between 0 and 1023
 * rawEnvelopeVolume: A number between 0 and 1023
 */
float getDbVolumeByRawVolume(float gain, int rawAudioVolume, int rawEnvelopeVolume) {
  // magic
  return ?
}
```

``` C++
#include <LapX9C10X.h>

#define SOUND_DETECTOR_AUDIO_PIN A0
#define SOUND_DETECTOR_ENVELOPE_PIN A1
#define POT_CS_PIN 8
#define POT_INC_PIN 9
#define POT_UD_PIN 10
LapX9C10X gainPot(POT_INC_PIN, POT_UD_PIN, POT_CS_PIN, LAPX9C10X_X9C104);

float gainDb = 33;

void setup() {
  Serial.begin(115200);
  pinMode(SOUND_DETECTOR_AUDIO_PIN, INPUT);
  pinMode(SOUND_DETECTOR_ENVELOPE_PIN, INPUT);
  gainPot.begin();
  float resistance = getResistanceByGain(gainDb);
  gainPot.set(gainDb);
}

void loop() {
  int rawAudioVolume = analogRead(SOUND_DETECTOR_AUDIO_PIN);
  int rawEnvelopeVolume = analogRead(SOUND_DETECTOR_ENVELOPE_PIN);

  float dbVolume = getDbVolumeByRawVolume(gainDb, rawAudioVolume, rawEnvelopeVolume);

  Serial.print("Volume:");
  Serial.println(dbVolume);
}

/**
 * gain: A number between 0 and 33
 * rawAudioVolume: A number between 0 and 1023
 * rawEnvelopeVolume: A number between 0 and 1023
 */
float getDbVolumeByRawVolume(float gain, int rawAudioVolume, int rawEnvelopeVolume) {
  // magic
  return ?
}

// Sparkfun sound detector dB<>resistance-interpolation based on Sparkfun's data set
// https://learn.sparkfun.com/tutorials/sound-detector-hookup-guide/configuration
float getResistanceByGain(float dB) {
  const float infinityOhms = 40.0f;
  const float dBTable[] = {0.0f, 6.0f, 13.0f, 19.0f, 25.0f, 30.0f, 33.0f, 40.0f};
  const float resistanceTable[] = {0.0f, 2.2f, 4.7f, 10.0f, 22.0f, 47.0f, 100.0f, INFINITY};

  // Check if the dB value is out of range
  if (dB < dBTable[0] || dB > dBTable[7])
    return -1.0f; // Return an error value or handle the case accordingly

  // Find the two nearest dB values in the table
  int index = 0;
  while (dB > dBTable[index + 1])
    index++;

  // Perform logarithmic interpolation
  float dB1 = dBTable[index];
  float dB2 = dBTable[index + 1];
  float resistance1 = resistanceTable[index];
  float resistance2 = resistanceTable[index + 1];

  float resistance = resistance1 * pow(10, ((dB - dB1) * log10(resistance2 / resistance1)) / (dB2 - dB1));
  return resistance / 1000.0f; // Return resistance in kilohms (K)
}
```

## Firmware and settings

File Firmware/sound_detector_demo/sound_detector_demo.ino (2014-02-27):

/******************************************************************************
 * sound_detector_demo.ino
 * Sound detector sample sketch
 * Byron Jacquot @ SparkFun Electronics
 * February 19, 2014
 * https://github.com/sparkfun/Sound_Detector
 * 
 * This sketch demonstrates the use of the Sparkfun Sound Detector board.
 *
 * The Sound Detector is a small board that combines a microphone and some 
 * processing circuitry.  It provides not only an audio output, but also a 
 * binary indication of the presence of sound and an analog representation 
 * of it's amplitude.  
 *
 * This sketch demonstrates two different modes of usage for the Sound
 * Detector.  The gate output (a binary indication that is high when sound
 * is present, and low when conditions are quiet) is used to fire a pin-change 
 * ISR, which lights an LED when the sound is present.  The envelope output 
 * (an analog voltage to rises to indicate the amplitude of the sound) is 
 * sampled in the loop(), and it prints an indication of the level to the 
 * serial terminal. 
 *
 * For more details about the Sound Detector, please check the hookup guide.
 *
 * Connections:
 * The Sound Detector is connected to the Adrduino as follows:
 * (Sound Detector -> Arduino pin)
 * GND → GND
 * VCC → 5V
 * Gate → Pin 2
 * Envelope → A0
 * 
 * Resources:
 * Additional library requirements: none
 * 
 * Development environment specifics:
 * Using Arduino IDe 1.0.5
 * Tested on Redboard, 3.3v/8MHz and 5v/16MHz ProMini hardware.
 * 
 * This code is beerware; if you see me (or any other SparkFun employee) at the
 * local, and you've found our code helpful, please buy us a round!
 * 
 * Distributed as-is; no warranty is given.
 ******************************************************************************/

 // Define hardware connections
#define PIN_GATE_IN 2
#define IRQ_GATE_IN  0
#define PIN_LED_OUT 13
#define PIN_ANALOG_IN A0

// soundISR()
// This function is installed as an interrupt service routine for the pin
// change interrupt.  When digital input 2 changes state, this routine
// is called.
// It queries the state of that pin, and sets the onboard LED to reflect that 
// pin's state.
void soundISR()
{
  int pin_val;
  
  pin_val = digitalRead(PIN_GATE_IN);
  digitalWrite(PIN_LED_OUT, pin_val);   
}

void setup()
{
  Serial.begin(9600);
  
  //  Configure LED pin as output
  pinMode(PIN_LED_OUT, OUTPUT);
  
  // configure input to interrupt
  pinMode(PIN_GATE_IN, INPUT);
  attachInterrupt(IRQ_GATE_IN, soundISR, CHANGE);

  // Display status
  Serial.println("Initialized");
}

void loop()
{
  int value;
  
  // Check the envelope input
  value = analogRead(PIN_ANALOG_IN);
  
  // Convert envelope value into a message
  Serial.print("Status: ");
  if(value <= 10)
  {
    Serial.println("Quiet.");
  }
  else if( (value > 10) && ( value <= 30) )
  {
    Serial.println("Moderate.");
  }
  else if(value > 30)
  {
    Serial.println("Loud.");
  }
  
  // pause for 1 second
  delay(1000);
}

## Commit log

2013-11-14 Initial checkin of schematic and PCB files
    [sound-detector.brd, sound-detector.sch]
2013-11-14 Updating 3k3 resistor to Sparkle part.
    [sound-detector.brd, sound-detector.sch, sound-detector_bom.ods]
2013-11-15 Fixed width of board outline.
    [sound-detector.brd]
2013-12-03 Changing resistor value convention.
    R12 changed from 3k3 to 3.3k.
    [sound-detector.brd, sound-detector.sch]
2013-12-10 Changes based on green board review
    -All text to vector
    -fixed diode footprint to diodes.inc recommendations
    --Added legend text for gain set resistors
    [sound-detector.brd, sound-detector.sch]
2013-12-16 Ready for reds
    Changed after group review:
    -net width of schem
    -Vector text
    -IC naming
    -Correct logos
    -Minor electrical cleanup
    [sound-detector.brd, sound-detector.sch]
2013-12-18 Added local board fiducials and paneled
    [sound-detector-Panel-v10.brd, sound-detector.brd, sound-detector.sch]
2014-02-22 Updating docs and firmware
    [gain-calc.ods]
2014-02-27 Prepping for go-live
    Added Fritzing sample and cleaned things up a bit.
    [Sound Detector analog.fzz]
2014-02-28 Updating repo organization
    [sound-detector_bom.ods]
2014-03-03 Fixing SJ1 silkscreen
    From Bug 8552: SJ1 had been labeled using the smash command, with the
    name moved from tNames to tPlace. Every board on the panel incremented
    it's value (SJ1, SJ2 up to SJ15).
    This makes the label on SJ1 a simple text object, which shouldn't
    increment for each instance on the panel.
    [sound-detector.brd]
2014-03-03 Rolling board rev number
    From V10 to V11
    [sound-detector.brd]
2014-03-04 changed fiducial from micro to regular
    [sound-detector-Panel-v10.brd, sound-detector.brd, sound-detector.sch]
2014-03-04 Created Panel v11
    v11 has the corrected silk
    [sound-detector-panel-v11.brd]
2016-10-31 Fixing incorrect version number on schematic
    [sound-detector.sch]
2017-07-21 New Big Panel
    [11872_sound-detector-big.panel-v11.brd]

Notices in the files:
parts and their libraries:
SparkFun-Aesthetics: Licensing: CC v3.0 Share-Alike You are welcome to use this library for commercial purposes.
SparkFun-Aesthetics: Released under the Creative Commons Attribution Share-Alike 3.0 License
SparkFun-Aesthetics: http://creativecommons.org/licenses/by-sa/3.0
